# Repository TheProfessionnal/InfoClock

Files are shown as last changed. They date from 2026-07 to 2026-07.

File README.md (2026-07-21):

# InfoClock v 0.5.7

A small and configurable clock project that displays some information on a LED display.

Configured for use with PlatformIO

## Features
* LED display for displaying information
* Temperature and forecast display using OpenWeatherMap
* Local temperature display (DS18B20)
* Embedded web server for configuration and monitoring
* Can log messages using syslog
* LHC Status display (using data from ALICE) (currently disabled, the LHC is off for maintenance)
* Currency exchange rate from http://fixer.io (disabled - broken due to API changes)
* Modular approach makes it easy to add new modules (tasks)
* Stateless messages, configurable with end/start date, displayable with countdown/count-up option.
* Temperature offset
* large alphabet
* 5 languages (english, french, spanish, portugese, german)

## Parts:
* CPU:      ESP8266 (WeMos D1 Mini or NodeMCU)
* Display:  8x8 pixel MAX7219-based display (currently 8 modules)
* DS18B20:  local temperature sensor

## Required libraries:

### Global:
* ESP8266HTTPClient
* ESP8266WebServer
* ESP8266Wifi
* Adarfuit GFX

### From Arduino library repo
* AJSP (https://github.com/bartoszbielawski/InfoClock)
* CPPTasks (https://github.com/bartoszbielawski/CPPTasks)
* LEDMatrixDisplay (https://github.com/bartoszbielawski/LEDMatrixDriver)

### Contributors
* Arkadiusz Gorzawski (https://github.com/agorzawski)

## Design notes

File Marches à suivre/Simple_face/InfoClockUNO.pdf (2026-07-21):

------- | 0.1 | DRAFT

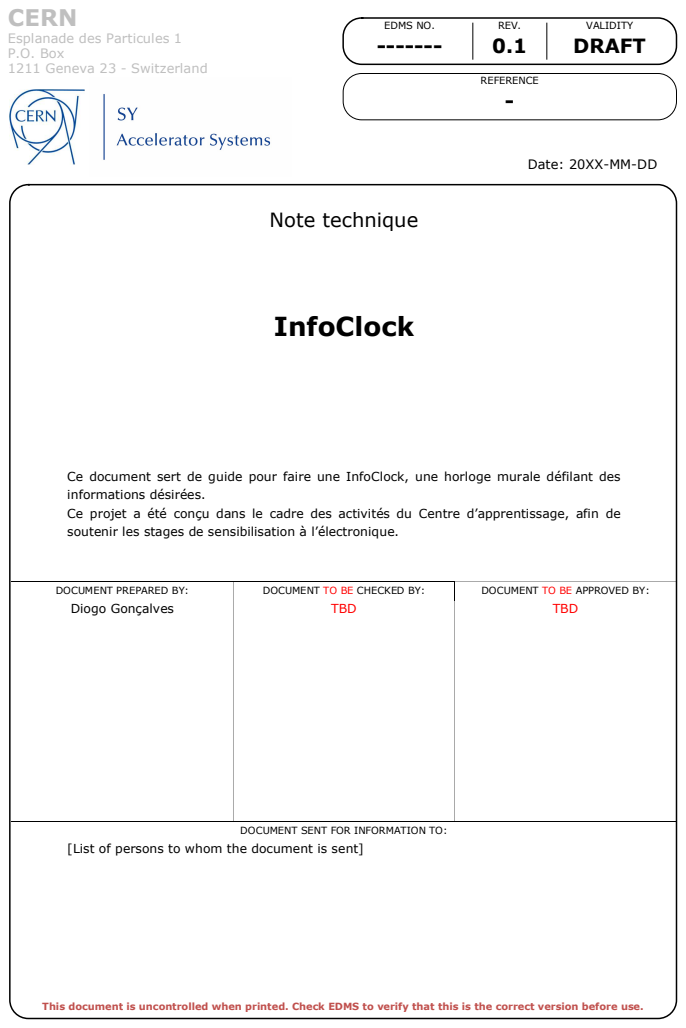
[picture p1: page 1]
EDMS NO.; REV.; VALIDITY; REFERENCE; Note technique; InfoClock; DOCUMENT PREPARED BY:; DOCUMENT TO BE CHECKED BY:; DOCUMENT TO BE APPROVED BY:; Diogo Gonçalves; TBD

CERN
Esplanade des Particules 1
P.O. Box
1211 Geneva 23 - Switzerland

Date: 20XX-MM-DD

Ce document sert de guide pour faire une InfoClock, une horloge murale défilant des
informations désirées.
Ce projet a été conçu dans le cadre des activités du Centre d’apprentissage, afin de
soutenir les stages de sensibilisation à l’électronique.

DOCUMENT SENT FOR INFORMATION TO:

[List of persons to whom the document is sent]

This document is uncontrolled when printed. Check EDMS to verify that this is the correct version before use.

REFERENCE | EDMS NO. | REV. | VALIDITY
- | ------- | 0.1 | DRAFT
Page 2 of 18

### HISTORY OF CHANGES

REV. NO. | DATE | PAGES | DESCRIPTIONS OF THE CHANGES
0.1 | 20xx-xx-x | n | Creation of the document.

Page 3 of 18

### TABLE OF CONTENTS

Page 4 of 18

## 1.Information

L’InfoClock est une horloge murale composée de 2 demi-displays, 1 module ESP8366 WEMOS, une sonde température et d’un boîtier imprimé en 3D.

Cette horloge fournit plusieurs informations, notamment l’heure, la date, la météo internet au choix (API Open Weather Map), température locale donnée par une sonde externe DS18B20. Elle permet aussi d’afficher des messages personnalisés.

Pour pouvoir faire correctement l’InfoClock il va falloir premièrement souder et câbler les displays, les connecter au WEMOS et ensuite programmer l’horloge.

Pour les nouveaux en électronique, prévoir une journée.

Fig 1: Photo de l’InfoClock

Page 5 of 18

Matériel | Catalogue | Nb.
BOITIER 3D | A IMPRIMER EN 3D AVANT !!! Via ce lien (impression 3D) | 1
WEMOS D1 MINI-V4.0 | Mauser.pt | 1
MAX7219 DISPLAY | Mauser.pt | 2
SONDE A TEMPERATURE DS18B20 | Mauser.pt | 1
VIS A TETES BOMBEES M2.5 x 10mm (Pour fermer le haut du boitier) | Vis à tête bombée à six pans creux / BN 8699 / 1727850 | 6
CABLE USB-A - MICRO-USB/USB-C | Mauser.pt | 1
PIN 1X2 (Pour doubler le VCC et GND) | 07.88.26.536.9 – EDH SCEM | 2
fer à souder et étain | | 1
Tresse à déssouder | | 1
Pince à dénuder | | 1
Pince plate | | 1
Clés imbus M2.5 et M3 | | 1
PC avec accès au réseau CERN | | 1
Smartphone | | 1

Page 6 of 18

## 2.Microcontrôleur

1) Insérer les barrettes dans le microcontrôleur.
2) Souder une seul des 8 pins de chaque barrette au microcontrôleur.
3) Metttre la barrette droite en refondant l’étain.
4) Souder le reste des PINs.

Fig 3 : Microcontroleur avec barrette pointées

Fig 2 : Microcontroleur avec barrettes non soudées

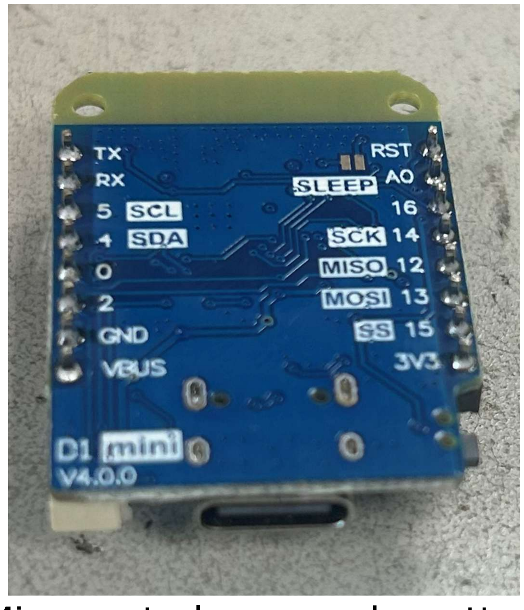
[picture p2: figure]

Fig 4 : Microcontroleur avec barrette soudées

Page 7 of 18

## 3.Sonde de température

1) Couper le câble à 20cm de la sonde.

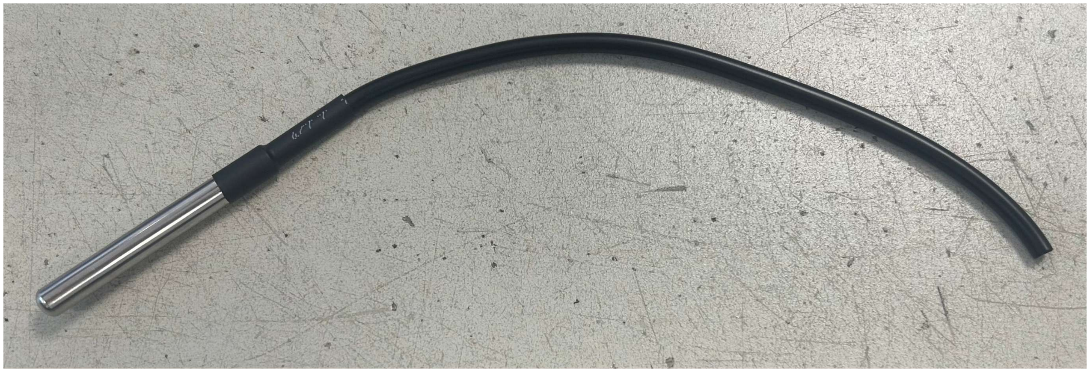
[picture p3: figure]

2) Assembler l’impression 3D.

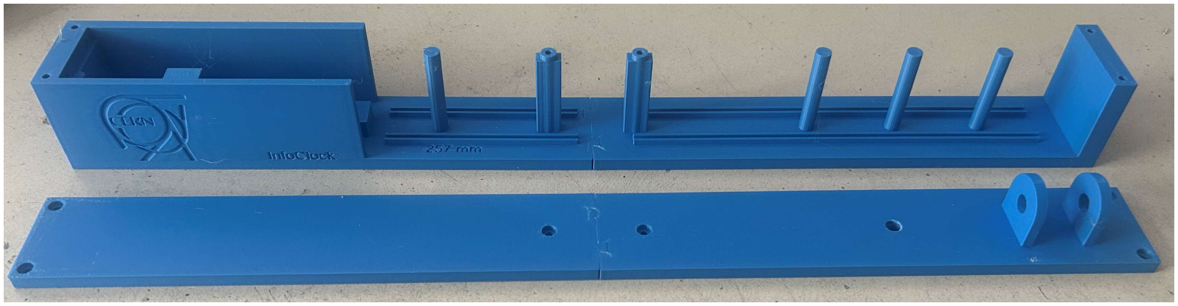
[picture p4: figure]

3) Mettre en place la sonde de température.

Fig 6 : Boitier assemblé

Fig 5 : Sonde de température coupée à 20 cm

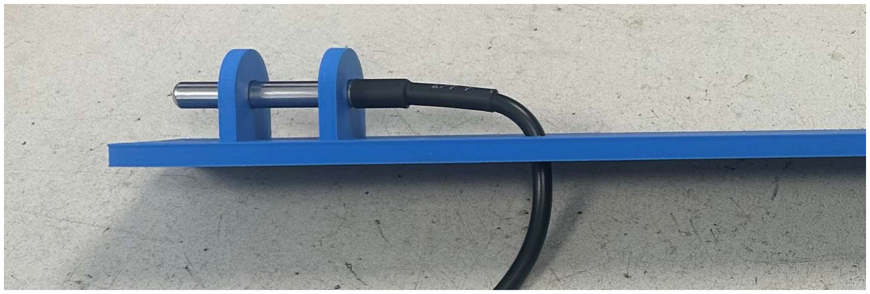
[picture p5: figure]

Fig 7 : Sonde de température insérée

Page 8 of 18
4) Dénuder le câble sur 5cm. Puis, dénuder chaque fil sur 0.5 cm. Enfin, torsader et ajouter de la brasure sur chaque fil.
5) Souder la sonde thermique au microcontrôleur selon le tableau ci-dessous.
Fils de la sonde de température | PINs du microcontrôleur
VCC/rouge | 3V3
GND/noir | D2 / 04
DIN/jaune | D3 / 00

Fig 8 : Fils de la sonde thermique dénudé

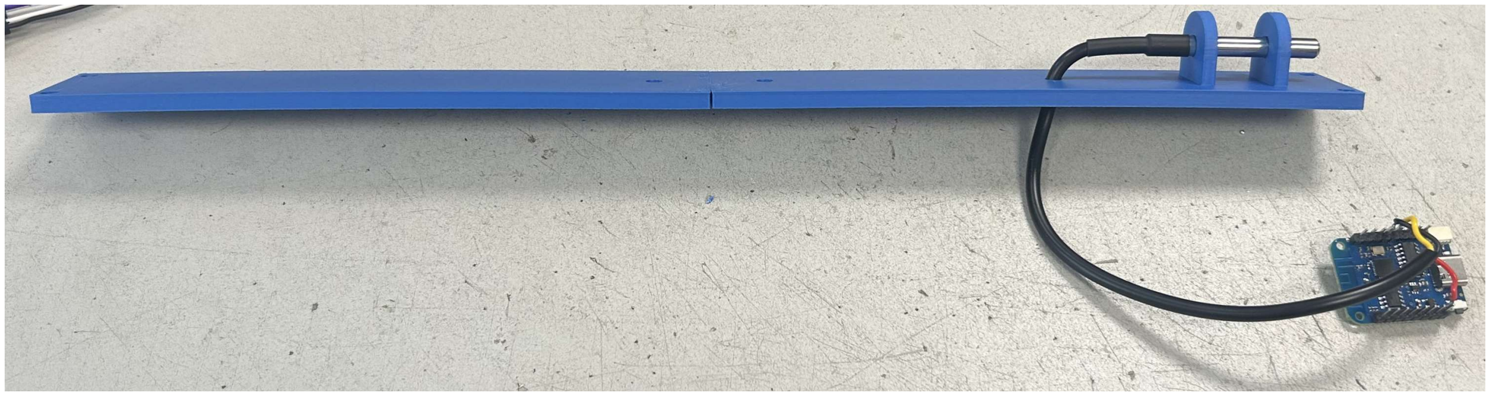
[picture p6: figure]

Fig 9 : Fils de la sonde soudée au microcontrôleur

Page 9 of 18

## 4.Displays

1) Commencer par retirer les matrices de LEDs aux extrémités.

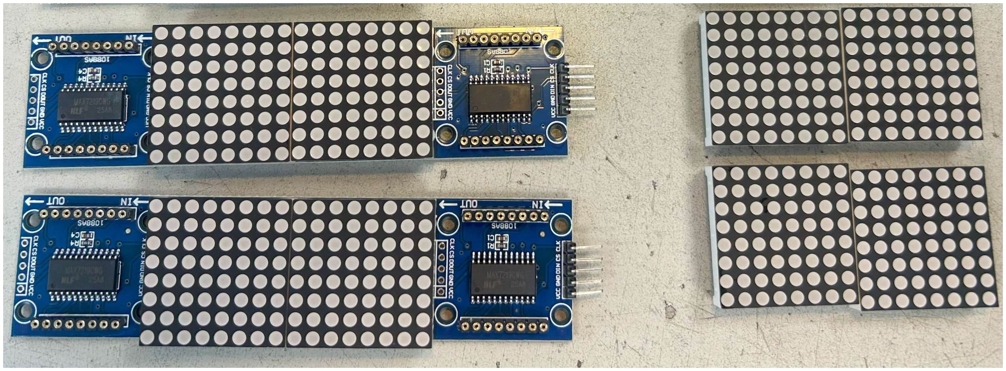
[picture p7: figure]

2) Assembler 2 displays 7219 entre eux en série pour avoir 1 grands displays.

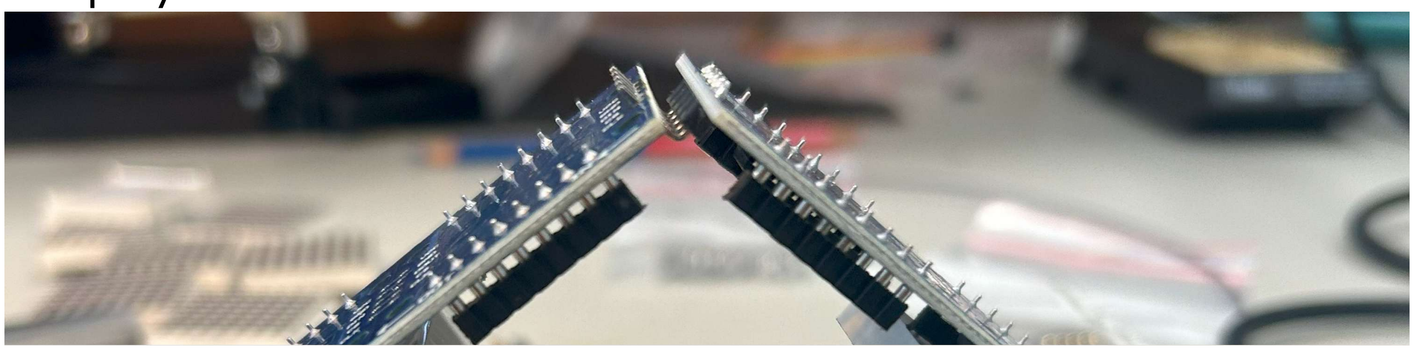
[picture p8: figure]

3) Tordre les PINs en mettant les écrans à plat.
4) Souder les PINs.

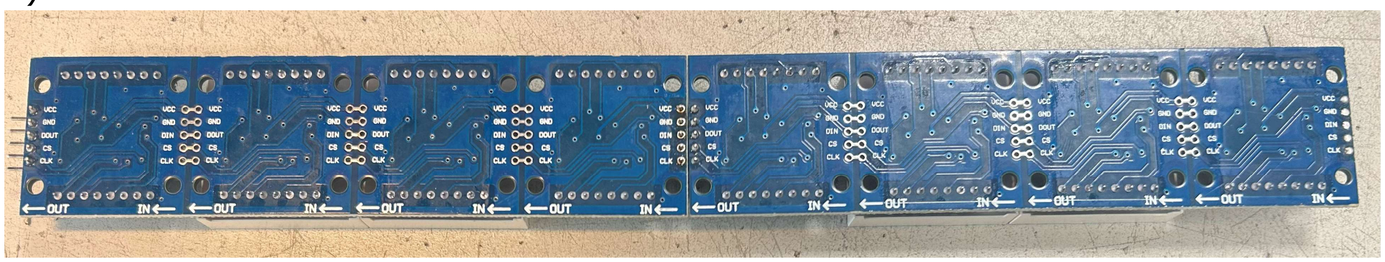
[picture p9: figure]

5) Remettre les matrices aux extrémités.

Fig. 10 : Ecrans sans matrices aux extrémités

Fig. 11 : Ecrans à angle droit avant soudure

Fig. 13 : Ecrans soudés

Fig. 12 : Ecrans à plat avant soudure

Page 10 of 18
7) Connecter selon le tableau ci-dessous au microcontrôleur.
Nom PINs displays | Noms PINs microcontroleur
Clk | D5 / 14
CS | D8 / 15
DIN | D7 / 13
GND | GND
VCC | VBUS / 5V
Pour une vue d’ensemble voir (Fig 14).

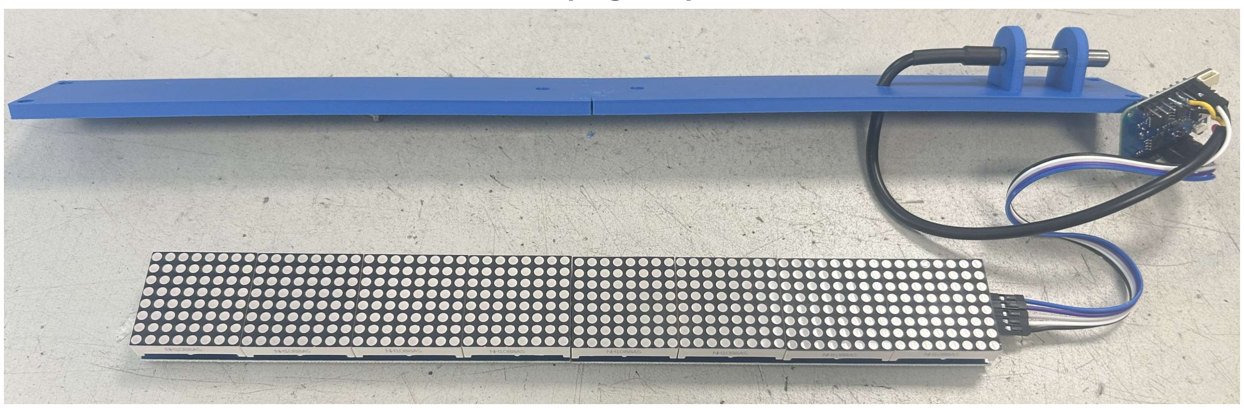
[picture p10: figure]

Fig. 14 : Ecran connecté

Page 11 of 18

## 5.Programmation

1) Brancher le microcontroleur au PC grâce au cable USB.
2) Sur un PC, télécharger Tasmota et firmware.bin.
3) Ouvrir Tasmota, si aucun port « COM » ne s’affiche (Fig. 15), rebrancher le cable USB sur un autre ports USB du PC. Puis, appuyer sur
« Refresh ».

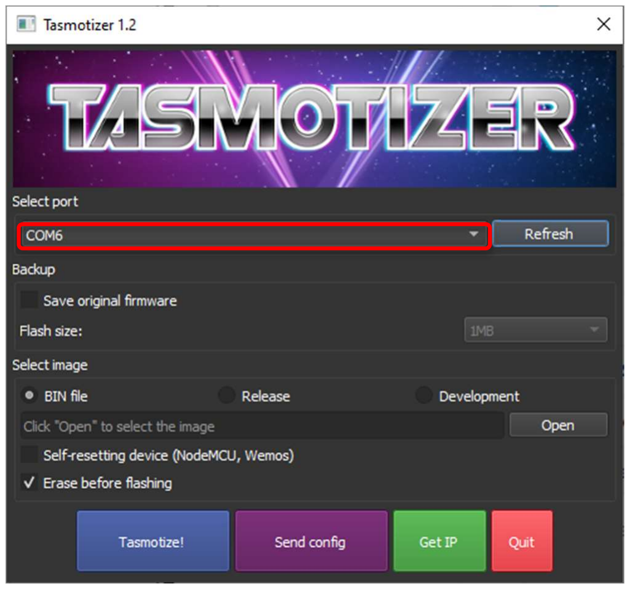
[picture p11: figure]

4) Clicker sur (BIN file –> open –> Download –> firmware.bin –> open –> Tasmotize!)

Le displays de l’infoclock doit maintenant afficher quelque chose.

Fig 16 : Tasmotatizer v1.2

Fig. 15 : Tasmotizer

Page 12 of 18
5) Sur le téléphone, se connecter au wifi « esp-display » (Fig. 17). Ensuite, chercher dans un navigateur web « 192.168.4.1 » (Fig. 18).

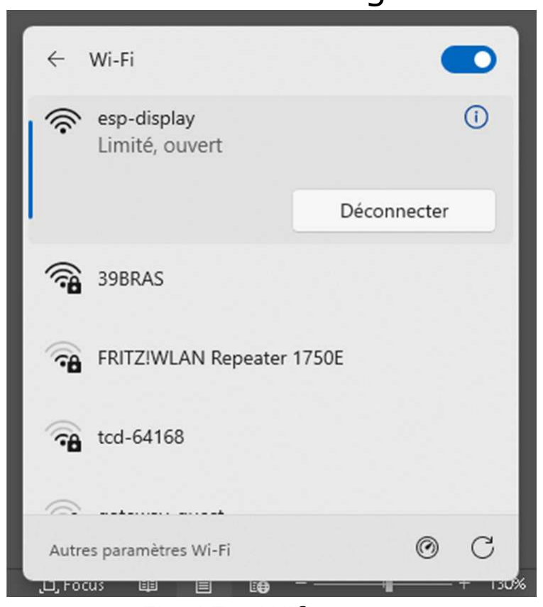
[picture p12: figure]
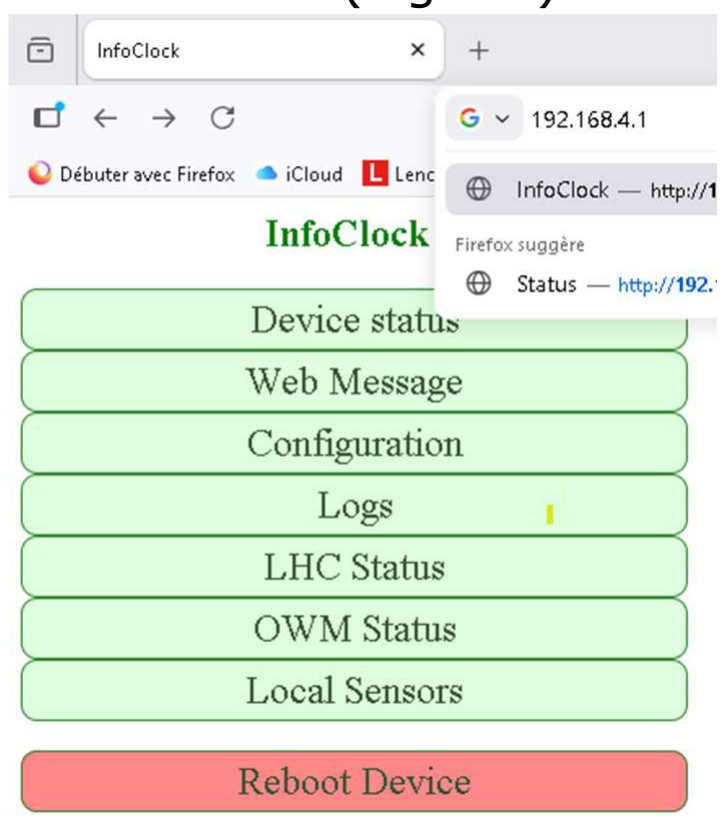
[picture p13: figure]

6) Dans l’interface du site clicker sur « Device status ». Puis, faire un screenshot.

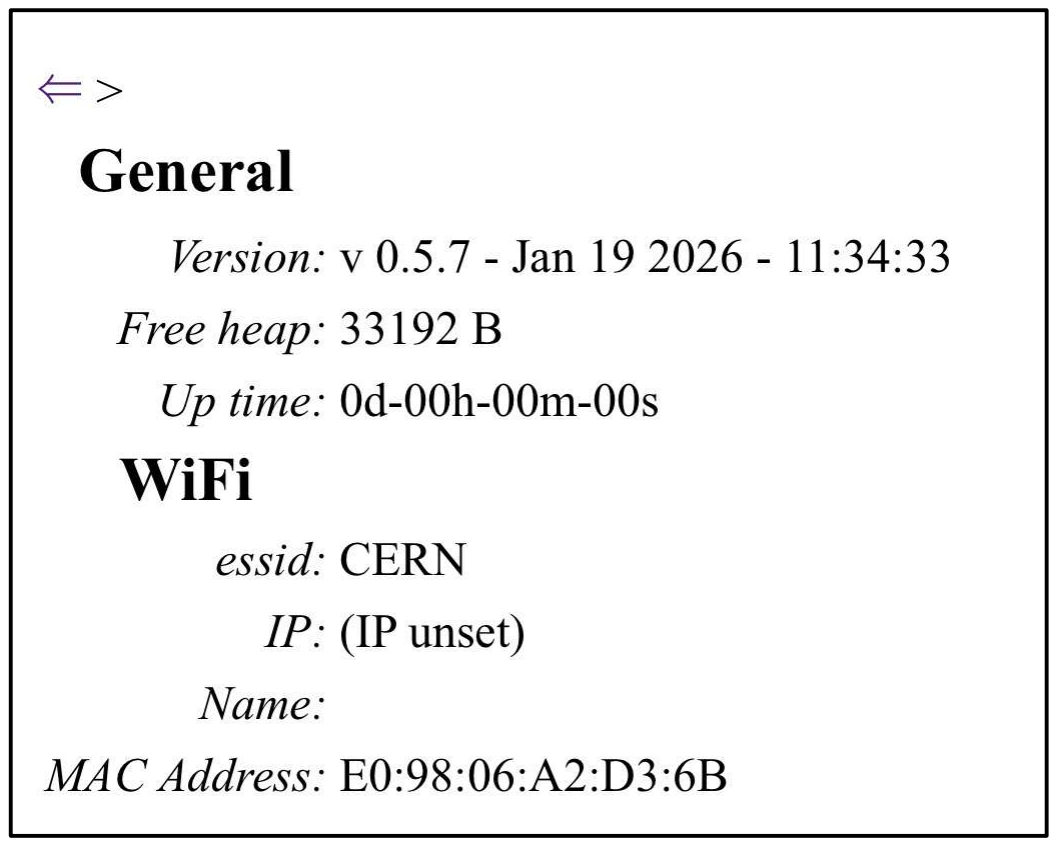
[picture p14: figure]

7) Revenir dans le menu, puis clicker sur « Configuration ». Une fenetre
8) apparait. Dans « Username », écrire « user », puis appuyer sur « Sign in ».
Fig 17 : Wifi manager | Fig 18 : Recherche Firefox

Fig 19 : Device status screenshot

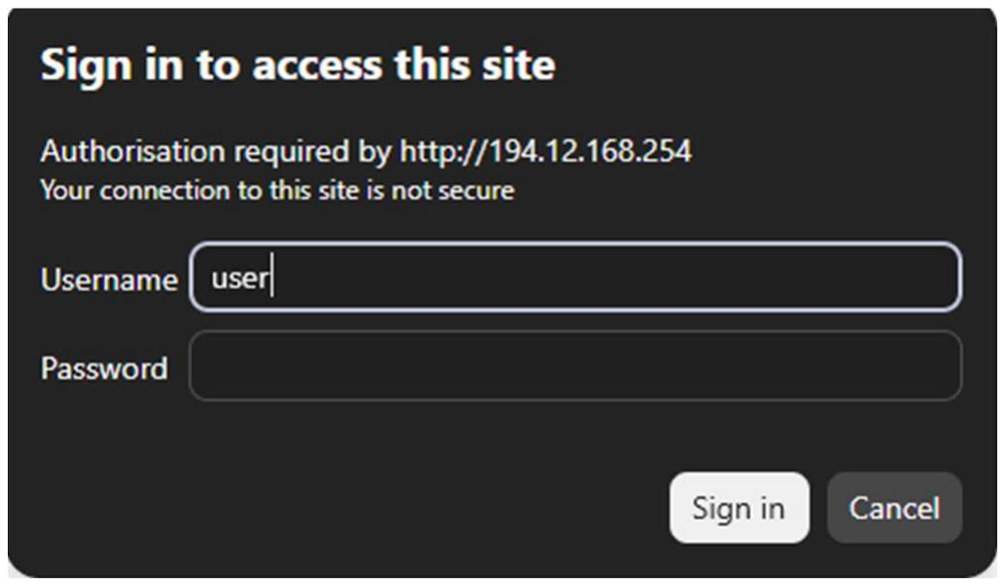
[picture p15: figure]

Fig 20 : access security

Page 13 of 18
9) Dans l’espace « Config », écrire « essid=CERN » et clicker sur « save ».
10) Sur le PC, clicker sur le lien LanDB Portal. Puis, compléter le champ suivant. Dans « Address », mettre la MAC-Adresse récupérée via le screenshot précédemment fait.

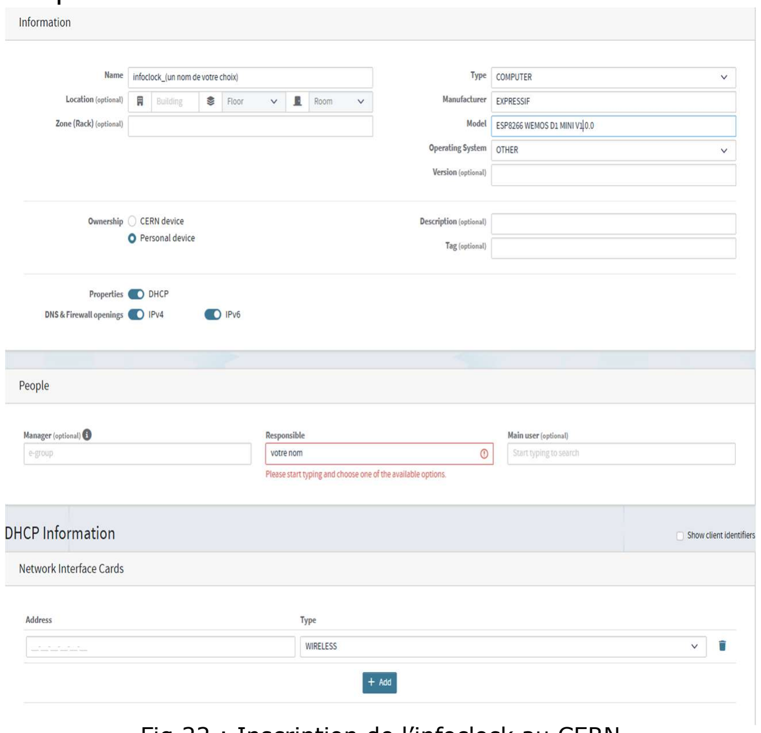
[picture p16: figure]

Fig 22 : Inscription de l’infoclock au CERN

Fig 21 : access security

Page 14 of 18
11) Clicker sur «», sous « Address ».

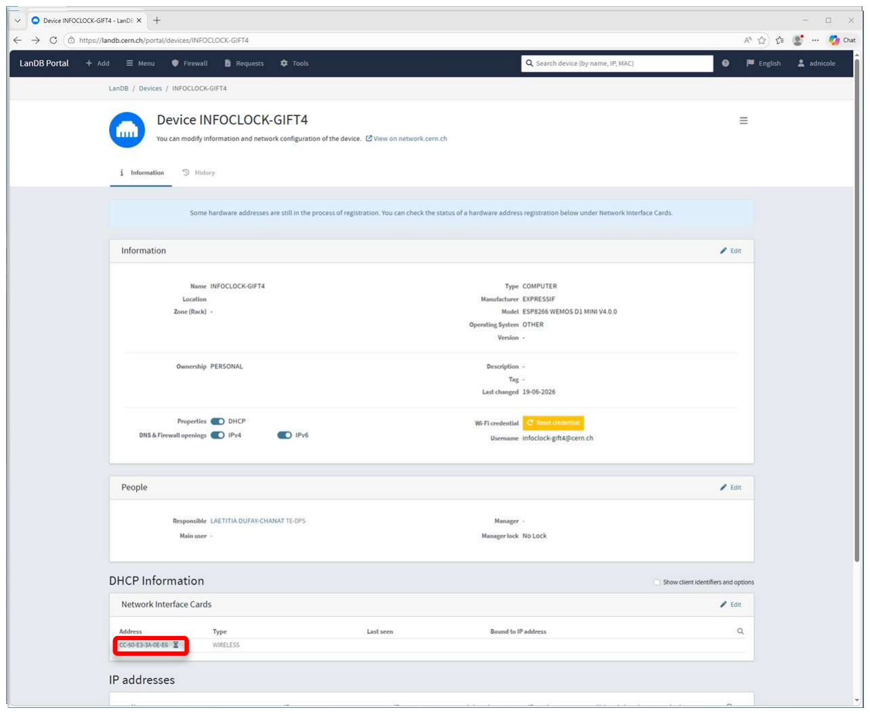
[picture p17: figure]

12) Garder de côter.

Fig 23 : Page d’informations de l’infoclock au CERN

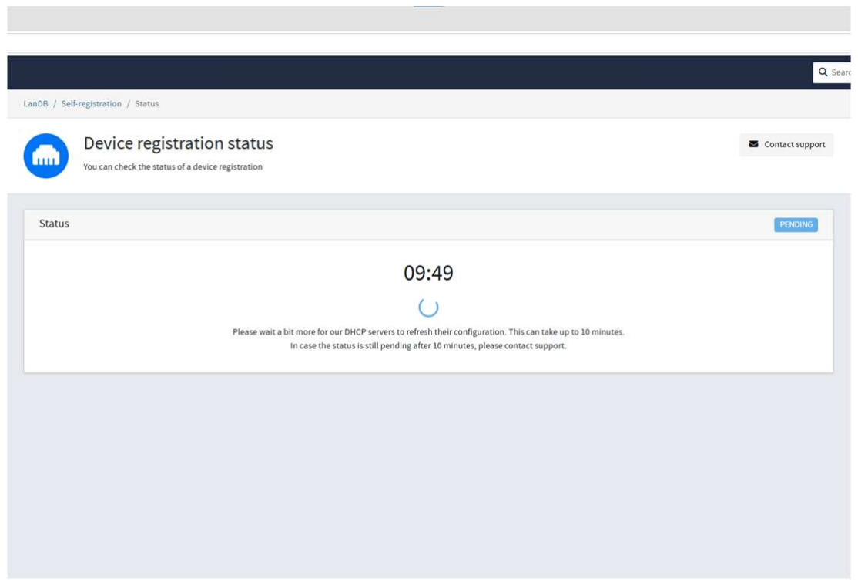
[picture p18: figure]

Fig 24 : Temps d’enregistrement

Page 15 of 18

## 6.Assemblage du boitier

1) Débrancher la prise USB du microntroleur et insérer le tout dans le boitier dans la base du boitier. Enfin, rebrancher.
2) On peut désormais fermer le boîtier avec les vis M2.5 x 10mm sur le dessus.

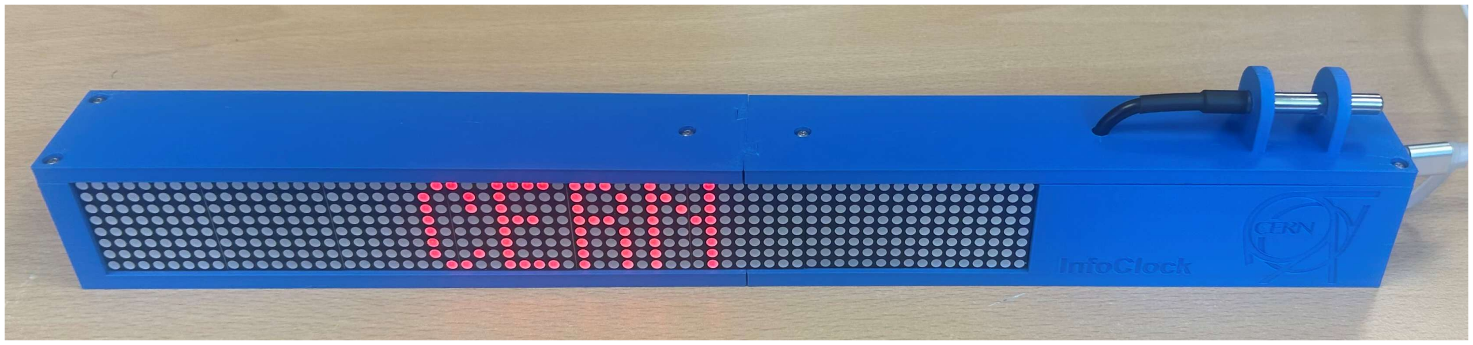
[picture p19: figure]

Fig 26 : Infoclock montée

Fig 25 : Infoclock ouverte

Page 16 of 18

## 7.Configuration

1) Attendre la fin du timer afficher sur le PC. Redémarrez l’infoclock en débranchant l’usb du PC, puis en le rebranchant et vérifier que l’infoclock affiche bien l’heure sinon refaire toute la partie « Programmation ».

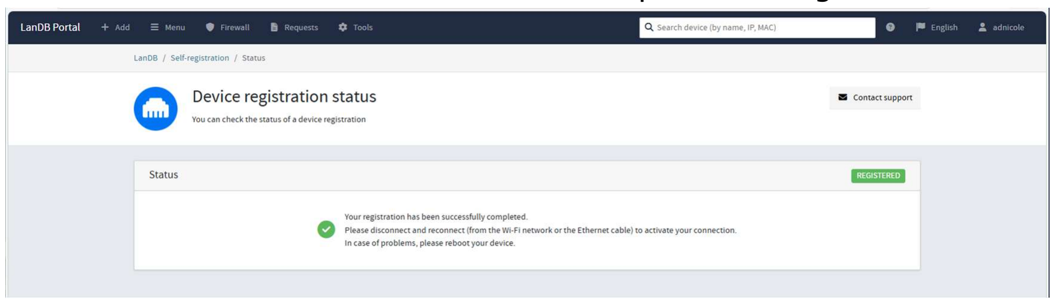
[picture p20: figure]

2) Redémarrer l’infoclock. Noter l’adresse IP qui s’affiche sur l’infoclock un moment après le démarrage. Conseil : prendre une photo.
3) Dans un navigateur web du PC, mettre l’adresse IP dans la barre de recherche.
4) Aller dans configuration.
5) Dans « Username », mettre « user », puis appuyer sur « Sign in ».

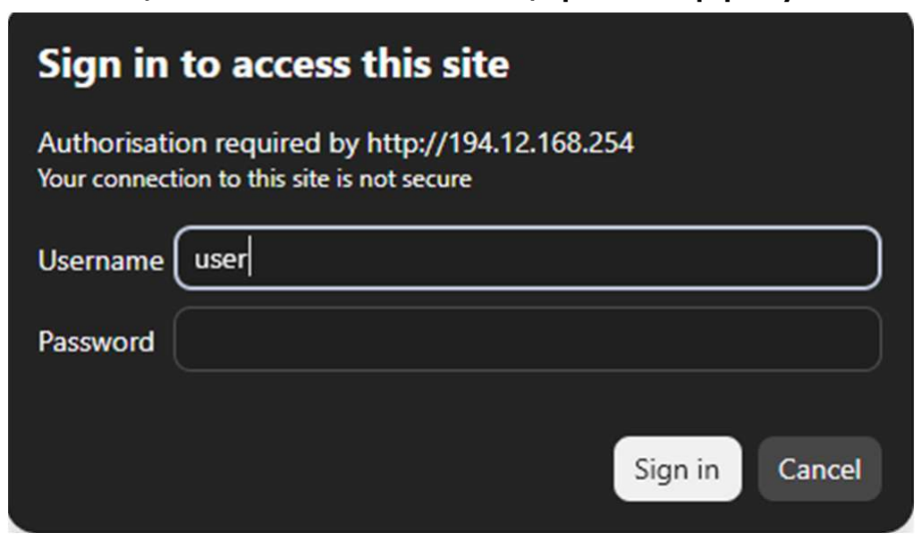
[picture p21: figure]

6) Ouvrez en parallèle le fichier Config télécharger précédemment. Faire Ctrl+a et Ctrl+c.

Fig 27 : Infoclock montée

Fig 28 : Infoclock montée

Fig 29 : access security

Page 17 of 18
7) Dans la fenêtre « Config » de l’InfoClock, faire Ctrl+a et Ctrl+v.

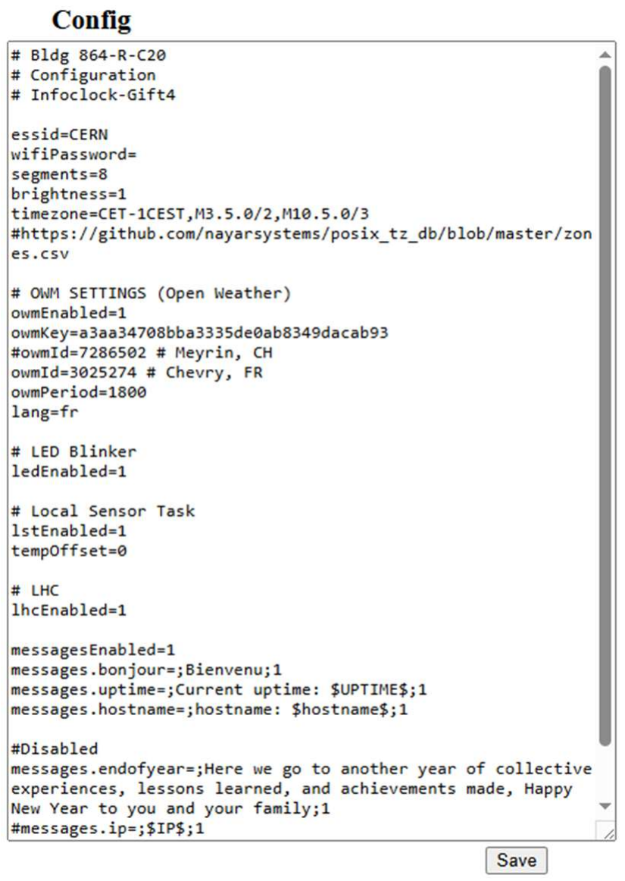
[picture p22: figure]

8) Noter le nom de votre infoclock.

Fig 30 : Config

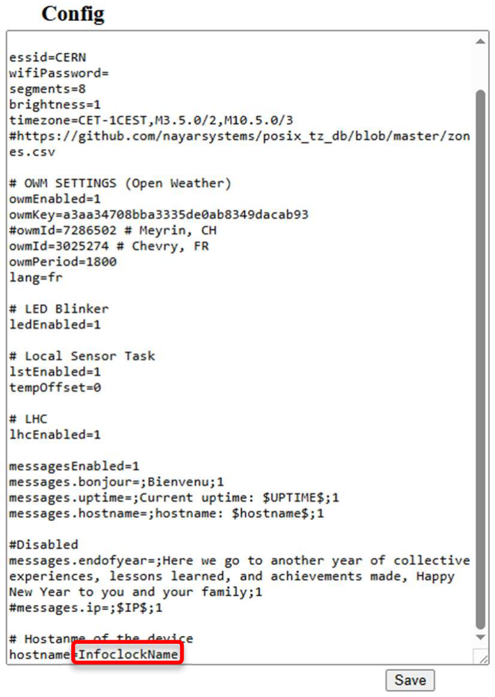
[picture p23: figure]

Fig 31 : Config

Page 18 of 18
9) Mettre le message de votre choix.

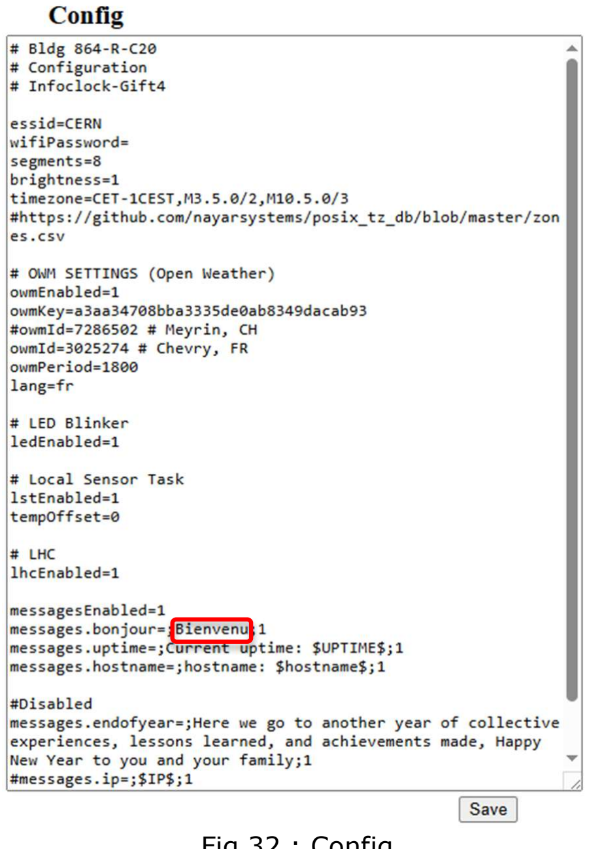
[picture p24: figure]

10) Clicker sur « save ». Revenir dans le menu et clicker sur « Reboot Device »

Fig 32 : Config

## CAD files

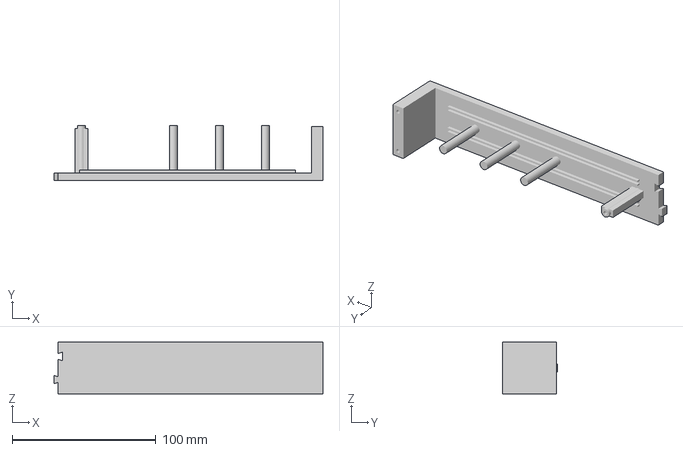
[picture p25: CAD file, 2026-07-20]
3D_models/double_face_257mm.stl/Body_right_rail.3mf
187.2 x 38.0 x 36.0 mm

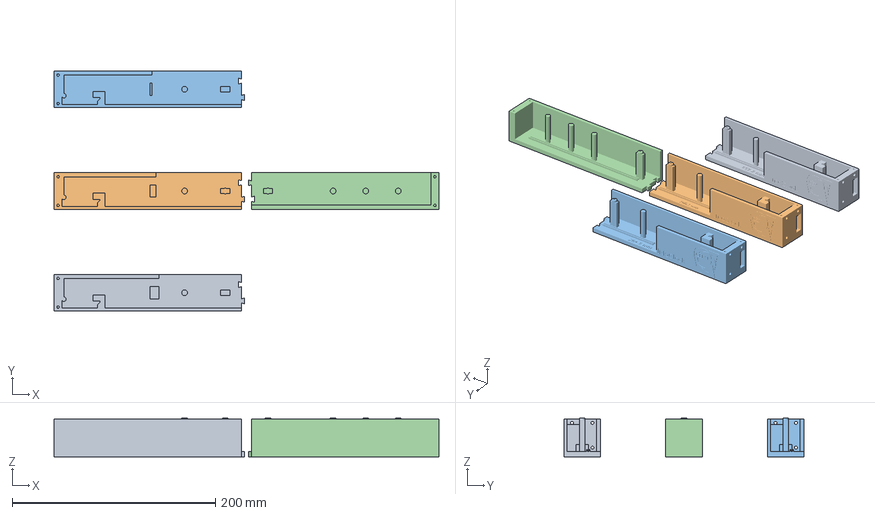
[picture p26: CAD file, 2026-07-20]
3D_models/simple_face_257mm.stl/Uno CERN.3mf
378.5 x 236.0 x 38.0 mm
Body_left ESP8266 257 Uno
Body_left ESP8266 260 Uno
Body_left ESP8266 264 Uno
Body_right Uno

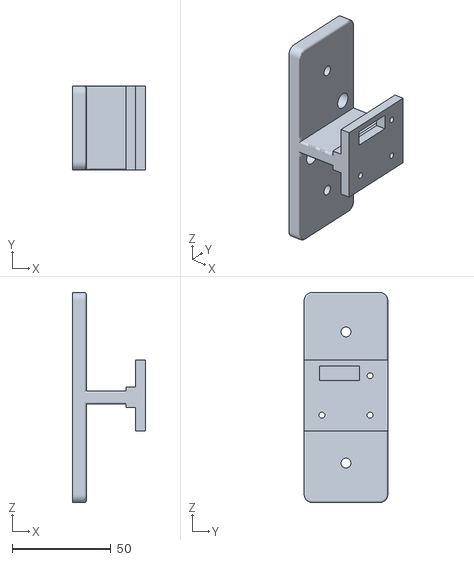
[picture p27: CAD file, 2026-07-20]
3D_models/wall_holders/WallHolder.milieu_de_mur.stl
37.0 x 42.4 x 106.5

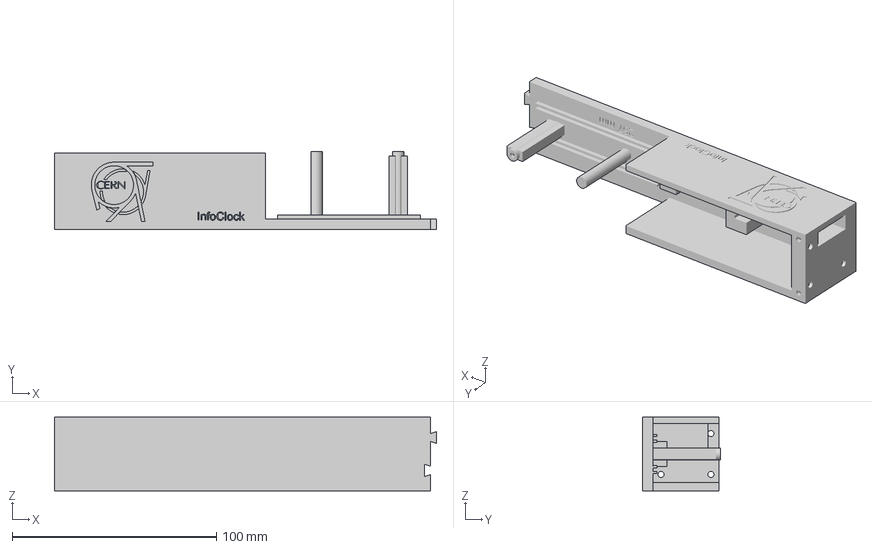
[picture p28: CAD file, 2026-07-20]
3D_models/double_face_257mm.stl/Body_left_rail.ESP8266.257mm.3mf
187.1 x 38.0 x 36.0 mm

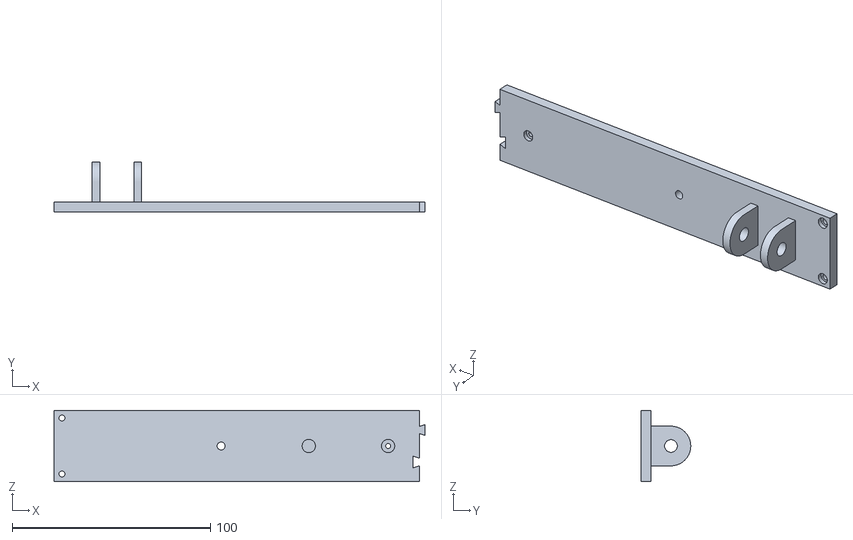
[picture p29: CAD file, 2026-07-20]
3D_models/simple_face_257mm.stl/Cover_left DS18B20.stl
187.0 x 25.0 x 36.0

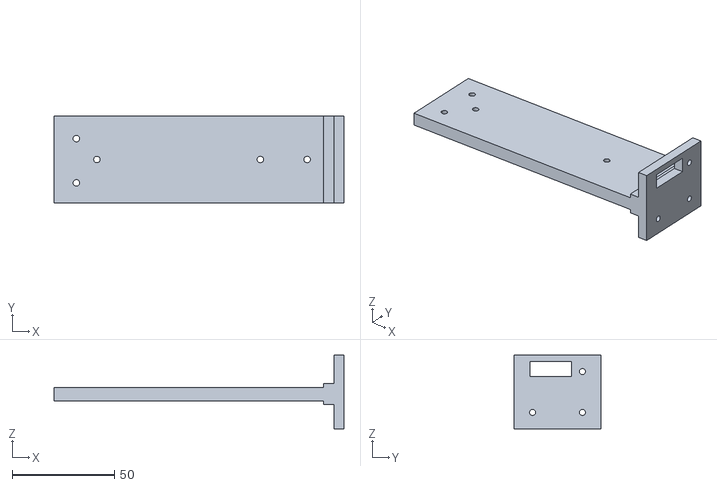
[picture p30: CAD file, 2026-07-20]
3D_models/wall_holders/WallHolder.angle_de_mur.stl
142.0 x 42.4 x 36.0

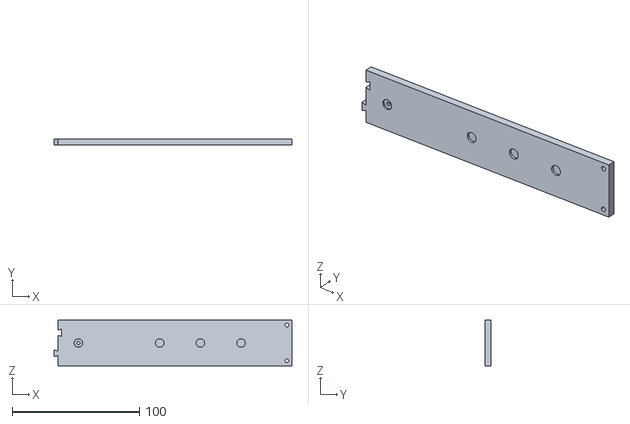
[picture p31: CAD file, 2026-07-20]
3D_models/double_face_257mm.stl/Cover_right.stl
187.3 x 5.02 x 36.0

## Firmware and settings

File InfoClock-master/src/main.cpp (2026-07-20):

#include "Arduino.h"
#include <time.h>
#include "sntp.h"

#include "config.h"

#include "tasks_utils.h"
#include "utils.h"
#include "OTA.hpp"
#include "SyslogSender.h"

#include "DisplayTask.hpp"

#include "ArduinoOTA.h"

using namespace Tasks;


void setup()
{
	Serial.begin(SERIAL_BAUD_RATE);

	checkFileSystem();

	readConfigFromFS();

	setupTasks();

	logPrintfX(F("MAIN"), F("MAC Address: %s"), WiFi.macAddress().c_str());

	auto& displayTask = DisplayTask::getInstance();

	displayTask.pushMessage("Initializing...", 2_s);
	displayTask.pushMessage(versionString, 0.4_s, true);

	syslogServer = readConfig(F("syslogServer"));

	configureOTA();
}

void loop()
{
	scheduleTasks();
	ArduinoOTA.handle();
}

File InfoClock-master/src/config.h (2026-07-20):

/*
 * config.h
 *
 *  Created on: 10.01.2017
 *      Author: Bartosz Bielawski
 */

#ifndef CONFIG_H_
#define CONFIG_H_

#include "Arduino.h"

const static uint8_t LBLUE = D4;

//SPI display configuration
//commented pins are hardware SPI
//LED_CLK = D5 - to clock (CLK)
//LED_MOSI = D7 - to data in (DIN)
const static uint8_t LED_CS = D8;		//to SS

//if you have two back-to-back connected displays put in series set it to 2
#define LED_DISPLAYS 1

const static int32_t MS_PER_CYCLE = 10;

//Local Sensor Task
const static uint8_t ONE_WIRE_TEMP = D3;
//use this define if you have no free ground pin and want to use some DIO
#define OW_GND D2

const static char versionString[] = "v 0.5.7";

const static char DEFAULT_USER[] = "user";

const static char HOSTNAME[] = "infoclock";

const static int SERIAL_BAUD_RATE = 115200;
#endif /* CONFIG_H_ */

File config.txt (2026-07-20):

# v5.8
# Bldg 864-R-C20
# Configuration
# InfoclockName

essid=CERN
wifiPassword=
segments=8
brightness=1
timezone=CET-1CEST,M3.5.0/2,M10.5.0/3
#https://github.com/nayarsystems/posix_tz_db/blob/master/zones.csv

# OWM SETTINGS (Open Weather)
owmEnabled=1
owmKey=a3aa34708bba3335de0ab8349dacab93
#owmId=7286502 # Meyrin, CH
owmId=3025274 # Chevry, FR
owmPeriod=1800
lang=fr

# LED Blinker
ledEnabled=1

# Local Sensor Task
lstEnabled=1
tempOffset=0

# LHC
lhcEnabled=1

messagesEnabled=1
messages.bonjour=;Bienvenu;1
messages.uptime=;Current uptime: $UPTIME$;1
messages.hostname=;hostname: $hostname$;1

#Disabled
messages.endofyear=;Here we go to another year of collective experiences, lessons learned, and achievements made, Happy New Year to you and your family;1
#messages.ip=;$IP$;1

# Hostanme of the device
hostname=pseudo
